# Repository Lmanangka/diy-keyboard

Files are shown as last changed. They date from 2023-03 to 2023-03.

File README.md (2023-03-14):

# diy-keyboard

Making and design my own keyboard from scratch

## Design and Components

### Front View Components

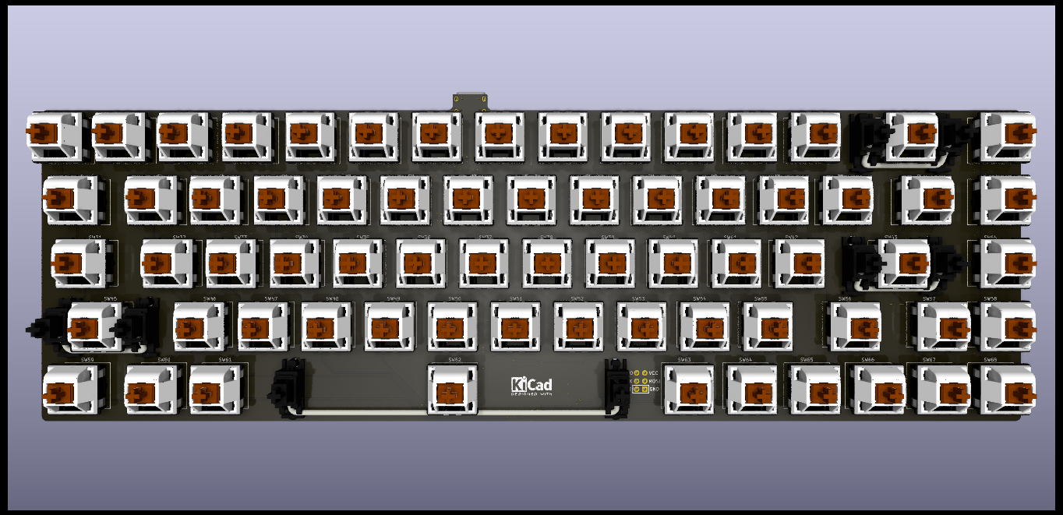
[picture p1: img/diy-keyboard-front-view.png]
Front view


- Switch Cherry MX
- Cherry MX Stabilizer(PCB mount stabs)

### Back View Components

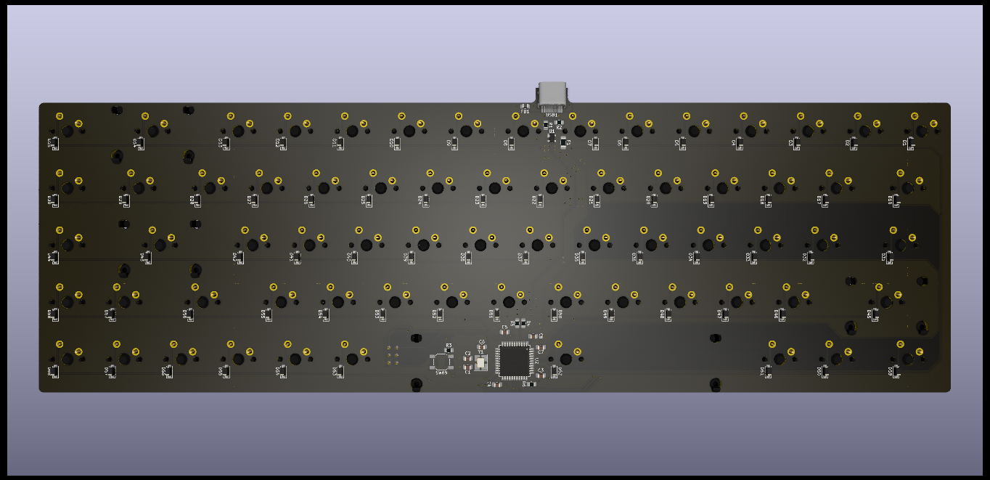
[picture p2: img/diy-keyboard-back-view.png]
Back view

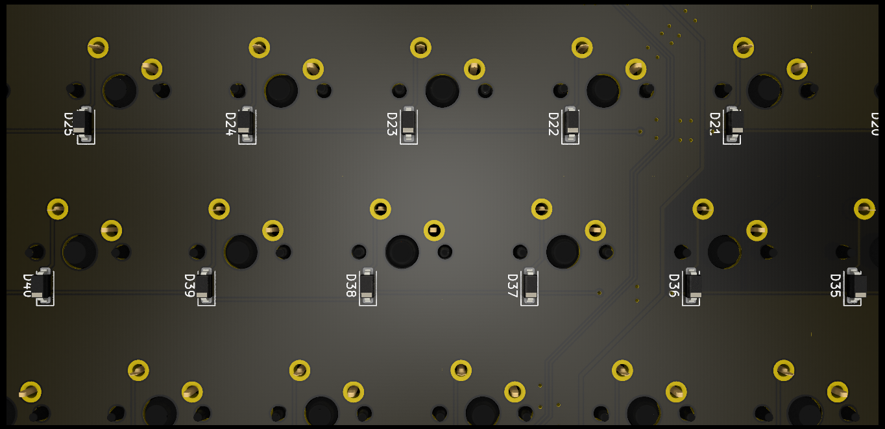
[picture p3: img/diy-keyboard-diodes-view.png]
Diodes view


- Diode 1N4148W

### MCU View Components

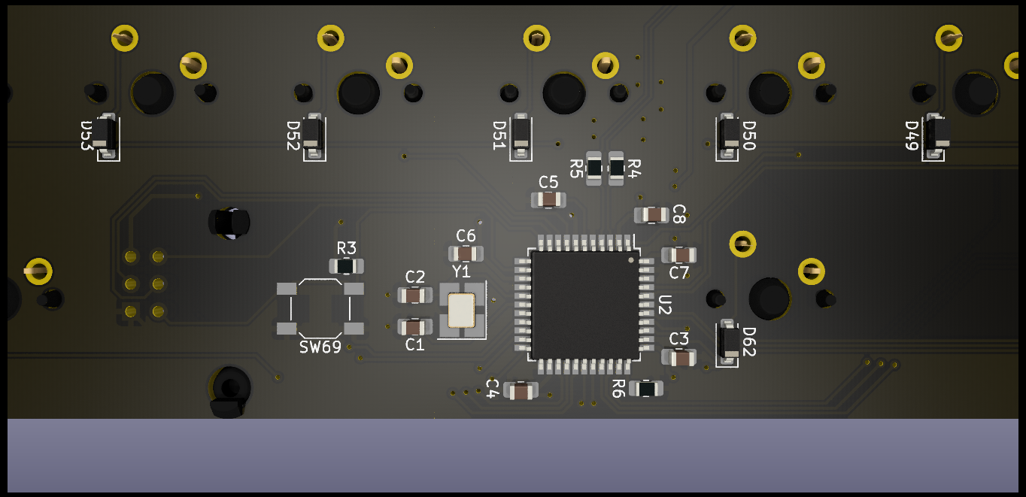
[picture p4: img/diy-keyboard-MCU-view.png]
MCU view


- U2 MCU ATmega32U4-AU
- Y1 Crystal oscilator 16MHz
- SW69 Reset Switch SKQG
- C1-C2 Capacitor 22pF
- C3-C7 Capacitor 0.1uF
- C8 Capacitor 10uF
- R3, R6 Resistor 10K Ohm
- R4-R5 Resistor 22 Ohm
- J1 AVR-ISP Connector

### USB-Type-C View Components

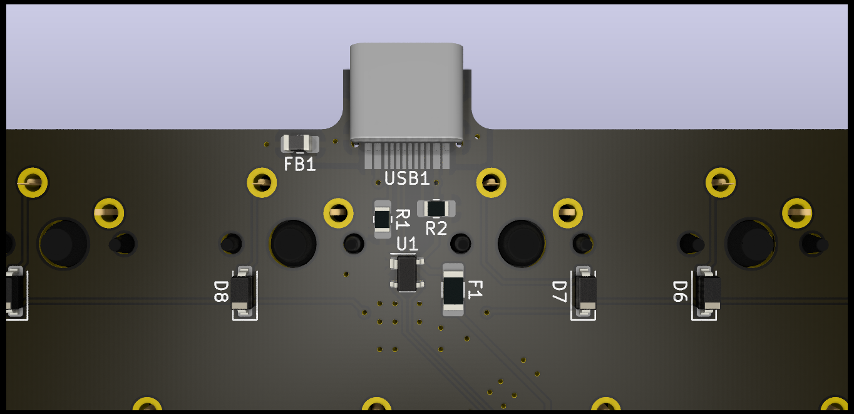
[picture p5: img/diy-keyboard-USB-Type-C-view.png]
USB view


- USB Type C
- FB1 Ferrite Bead
- R1-R2 Resistor 5.1K Ohm
- F1 PTC Fuse 500mA
- U1 PRTR5V0U2X

## Footprints Source

- [Switch and stabilizer](https://github.com/perigoso/keyswitch-kicad-library)
- [USB Type C](https://github.com/ai03-2725/Type-C.pretty)

## References And Credit

- [Designing a keyboard from scratch](https://www.masterzen.fr/2020/05/03/designing-a-keyboard-part-1)(mostly I used this as guide)
- [PCB Designer Guide](https://wiki.ai03.com/books/pcb-design/chapter/pcb-designer-guide)(starting point)
- [keyboard-pcb-guide](https://github.com/ruiqimao/keyboard-pcb-guide)(for reference)

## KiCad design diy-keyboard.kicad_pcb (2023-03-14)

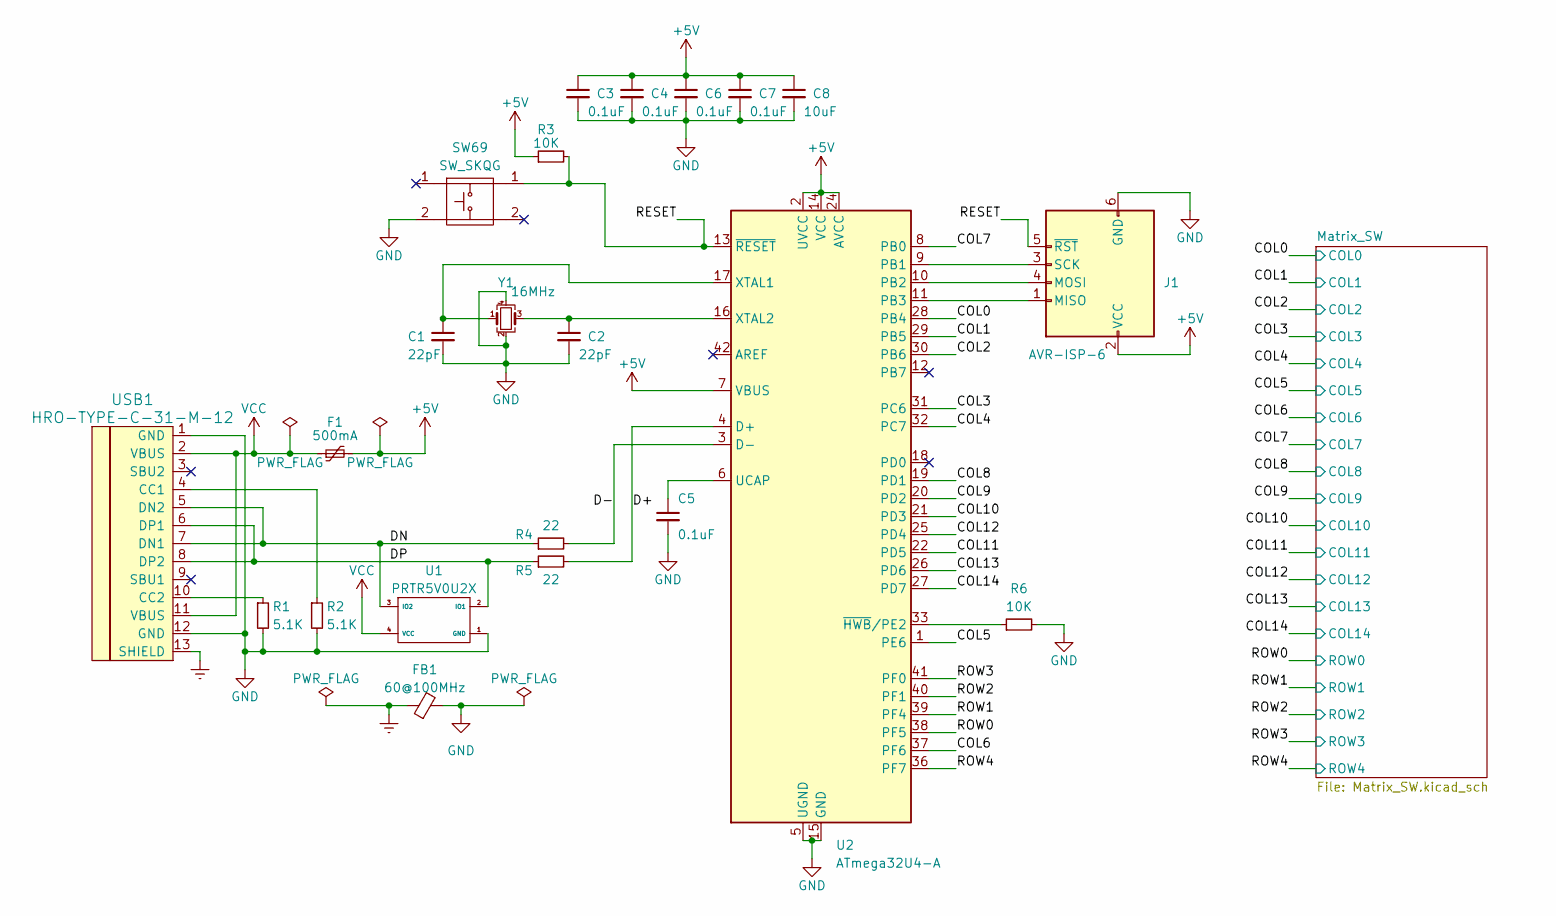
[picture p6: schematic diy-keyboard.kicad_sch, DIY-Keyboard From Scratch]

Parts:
C1, C2: 22pF; C_0805_2012Metric_Pad1.18x1.45mm_HandSolder
C3, C4, C5, C6, C7: 0.1uF; C_0805_2012Metric_Pad1.18x1.45mm_HandSolder
C8: 10uF; C_0805_2012Metric_Pad1.18x1.45mm_HandSolder
F1: 500mA; Fuse_1206_3216Metric_Pad1.42x1.75mm_HandSolder
FB1: 60@100MHz; L_0805_2012Metric_Pad1.15x1.40mm_HandSolder
J1: AVR-ISP-6; Reset_Pretty-Mask
R1, R2: 5.1K; R_0805_2012Metric_Pad1.20x1.40mm_HandSolder
R3, R6: 10K; R_0805_2012Metric_Pad1.20x1.40mm_HandSolder
R4, R5: 22; R_0805_2012Metric_Pad1.20x1.40mm_HandSolder
SW69: SW_SKQG; SW_SPST_SKQG_WithStem
U1: PRTR5V0U2X; SOT-143
U2: ATmega32U4-A; TQFP-44_10x10mm_P0.8mm
USB1: HRO-TYPE-C-31-M-12; HRO-TYPE-C-31-M-12-HandSoldering
Y1: 16MHz; Crystal_SMD_3225-4Pin_3.2x2.5mm_HandSoldering

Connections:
+5V: C3.1, C4.1, C6.1, C7.1, C8.1, F1.2, J1.2 (VCC), R3.1, U2.2 (UVCC), U2.7 (VBUS), U2.14 (VCC), U2.24 (AVCC), U2.34 (VCC), U2.44 (AVCC)
/COL0: U2.28 (PB4); also elsewhere on the board
/COL1: U2.29 (PB5); also elsewhere on the board
/COL2: U2.30 (PB6); also elsewhere on the board
/COL3: U2.31 (PC6); also elsewhere on the board
/COL4: U2.32 (PC7); also elsewhere on the board
/COL5: U2.1 (PE6); also elsewhere on the board
/COL6: U2.37 (PF6); also elsewhere on the board
/COL7: U2.8 (PB0); also elsewhere on the board
/COL8: U2.19 (PD1); also elsewhere on the board
/COL9: U2.20 (PD2); also elsewhere on the board
/COL10: U2.21 (PD3); also elsewhere on the board
/COL11: U2.22 (PD5); also elsewhere on the board
/COL12: U2.25 (PD4); also elsewhere on the board
/COL13: U2.26 (PD6); also elsewhere on the board
/COL14: U2.27 (PD7); also elsewhere on the board
/D+: R5.2, U2.4 (D+)
/D-: R4.2, U2.3 (D-)
/DN: R4.1, U1.3 (IO2), USB1.5 (DN2), USB1.7 (DN1)
/DP: R5.1, U1.2 (IO1), USB1.6 (DP1), USB1.8 (DP2)
/RESET: J1.5 (~RST), R3.2, SW69.1, U2.13 (~RESET)
/ROW0: U2.38 (PF5); also elsewhere on the board
/ROW1: U2.39 (PF4); also elsewhere on the board
/ROW2: U2.40 (PF1); also elsewhere on the board
/ROW3: U2.41 (PF0); also elsewhere on the board
/ROW4: U2.36 (PF7); also elsewhere on the board
Earth: FB1.1, USB1.13 (SHIELD)
GND: C1.2, C2.2, C3.2, C4.2, C5.2, C6.2, C7.2, C8.2, FB1.2, J1.6 (GND), R1.2, R2.2, R6.2, SW69.2, U1.1 (GND), U2.5 (UGND), U2.15 (GND), U2.23 (GND), U2.35 (GND), U2.43 (GND), USB1.1 (GND), USB1.12 (GND), Y1.2, Y1.4
unnamed: J1.1 (MISO), U2.11 (PB3)
unnamed: J1.4 (MOSI), U2.10 (PB2)
unnamed: J1.3 (SCK), U2.9 (PB1)
unnamed: C5.1, U2.6 (UCAP)
unnamed: C1.1, U2.17 (XTAL1), Y1.1
unnamed: C2.1, U2.16 (XTAL2), Y1.3
unnamed: R6.1, U2.33 (~HWB/PE2)
unnamed: R2.1, USB1.4 (CC1)
unnamed: R1.1, USB1.10 (CC2)
VCC: F1.1, U1.4 (VCC), USB1.2 (VBUS), USB1.11 (VBUS)

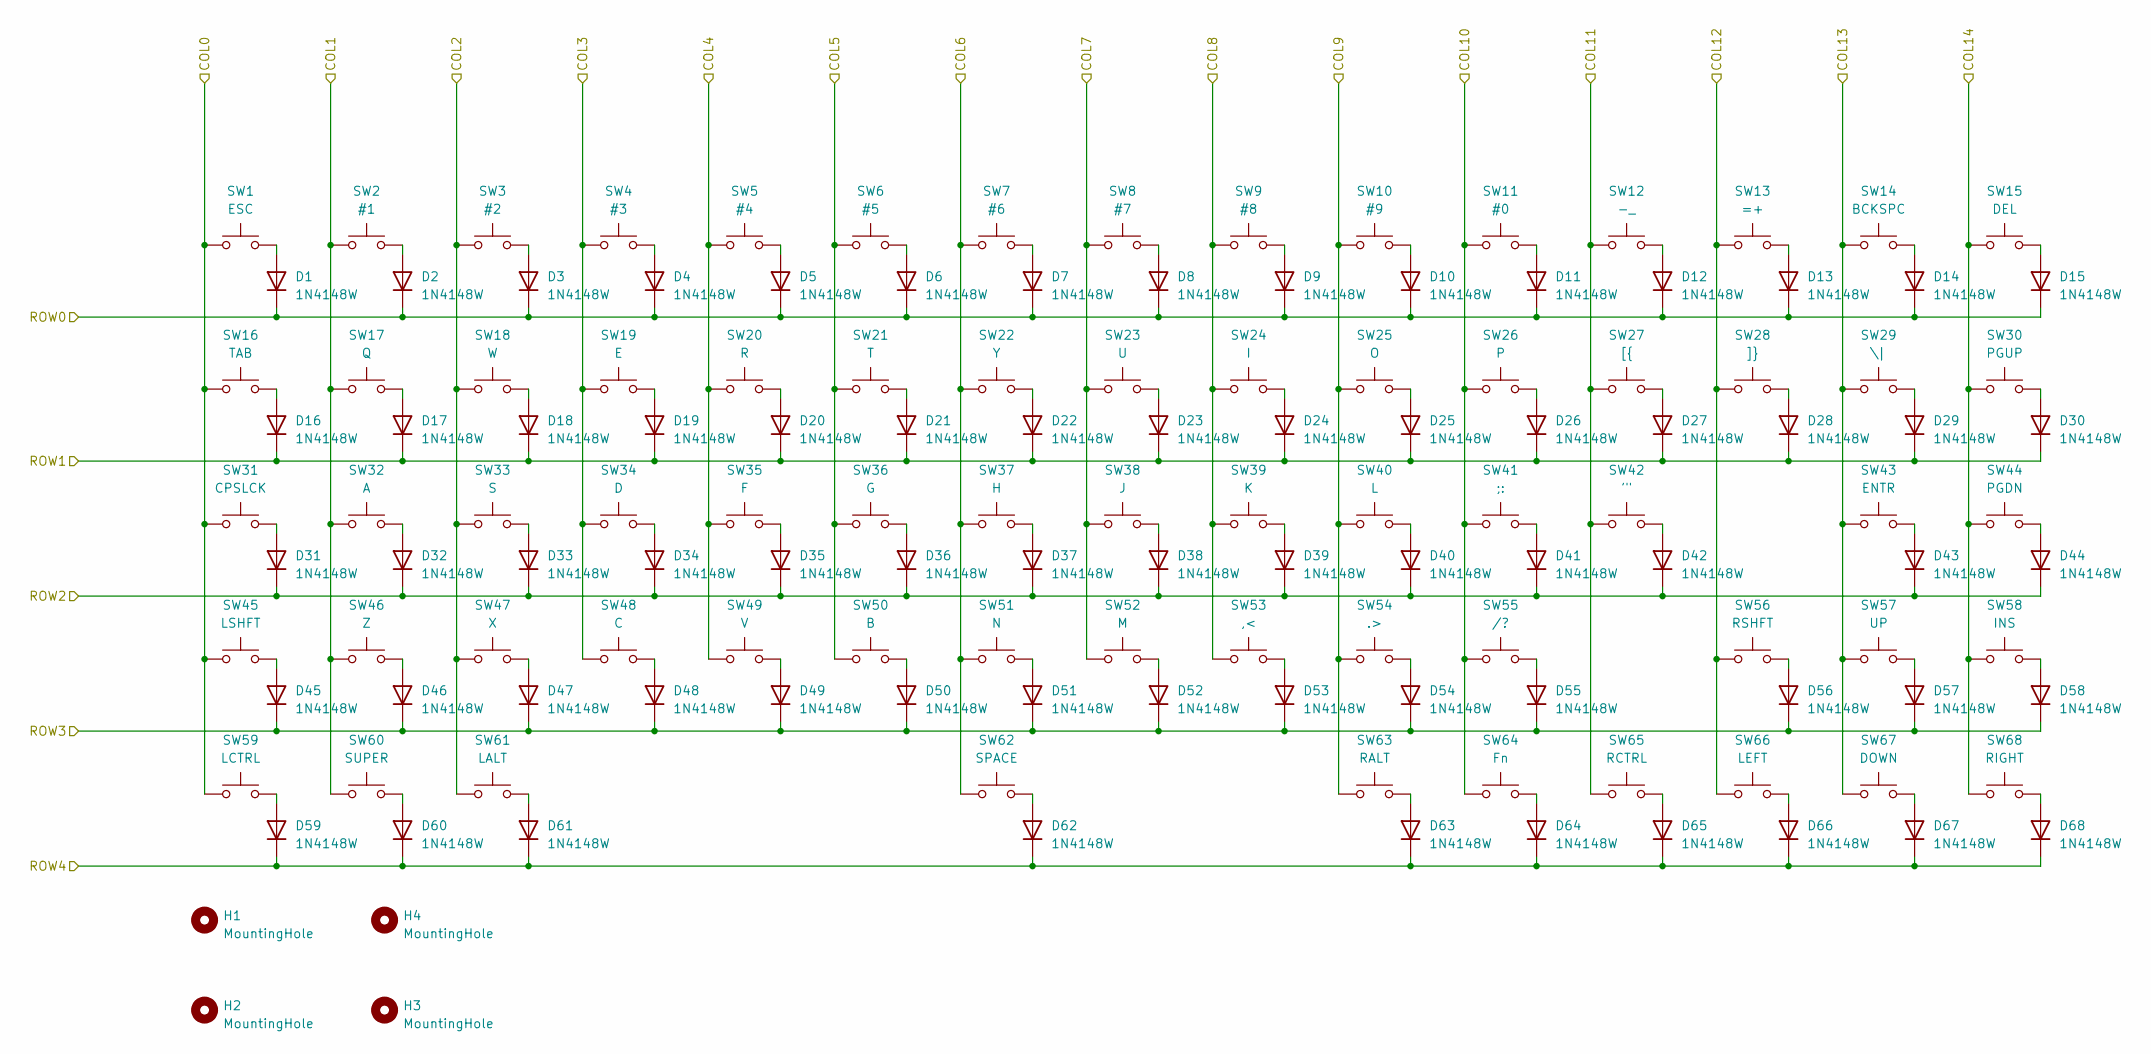
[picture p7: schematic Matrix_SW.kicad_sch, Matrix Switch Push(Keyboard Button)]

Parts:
D1, D2, D3, D4, D5, D6, D7, D8, D9, D10, D11, D12, D13, D14, D15, D16, D17, D18, D19, D20, D21, D22, D23, D24, D25, D26, D27, D28, D29, D30, D31, D32, D33, D34, D35, D36, D37, D38, D39, D40, D41, D42, D43, D44, D45, D46, D47, D48, D49, D50, D51, D52, D53, D54, D55, D56, D57, D58, D59, D60, D61, D62, D63, D64, D65, D66, D67, D68: 1N4148W; D_SOD-123
H1: MountingHole; Stabilizer_Cherry_MX_6.25u
H2, H3, H4: MountingHole; Stabilizer_Cherry_MX_2.00u
SW1: ESC; SW_Cherry_MX_PCB_1.00u
SW2: #1; SW_Cherry_MX_PCB_1.00u
SW3: #2; SW_Cherry_MX_PCB_1.00u
SW4: #3; SW_Cherry_MX_PCB_1.00u
SW5: #4; SW_Cherry_MX_PCB_1.00u
SW6: #5; SW_Cherry_MX_PCB_1.00u
SW7: #6; SW_Cherry_MX_PCB_1.00u
SW8: #7; SW_Cherry_MX_PCB_1.00u
SW9: #8; SW_Cherry_MX_PCB_1.00u
SW10: #9; SW_Cherry_MX_PCB_1.00u
SW11: #0; SW_Cherry_MX_PCB_1.00u
SW12: -_; SW_Cherry_MX_PCB_1.00u
SW13: =+; SW_Cherry_MX_PCB_1.00u
SW14: BCKSPC; SW_Cherry_MX_PCB_2.00u
SW15: DEL; SW_Cherry_MX_PCB_1.00u
SW16: TAB; SW_Cherry_MX_PCB_1.50u
SW17: Q; SW_Cherry_MX_PCB_1.00u
SW18: W; SW_Cherry_MX_PCB_1.00u
SW19: E; SW_Cherry_MX_PCB_1.00u
SW20: R; SW_Cherry_MX_PCB_1.00u
SW21: T; SW_Cherry_MX_PCB_1.00u
SW22: Y; SW_Cherry_MX_PCB_1.00u
SW23: U; SW_Cherry_MX_PCB_1.00u
SW24: I; SW_Cherry_MX_PCB_1.00u
SW25: O; SW_Cherry_MX_PCB_1.00u
SW26: P; SW_Cherry_MX_PCB_1.00u
SW27: [{; SW_Cherry_MX_PCB_1.00u
SW28: ]}; SW_Cherry_MX_PCB_1.00u
SW29: \|; SW_Cherry_MX_PCB_1.50u
SW30: PGUP; SW_Cherry_MX_PCB_1.00u
SW31: CPSLCK; SW_Cherry_MX_PCB_1.75u
SW32: A; SW_Cherry_MX_PCB_1.00u
SW33: S; SW_Cherry_MX_PCB_1.00u
SW34: D; SW_Cherry_MX_PCB_1.00u
SW35: F; SW_Cherry_MX_PCB_1.00u
SW36: G; SW_Cherry_MX_PCB_1.00u
SW37: H; SW_Cherry_MX_PCB_1.00u
SW38: J; SW_Cherry_MX_PCB_1.00u
SW39: K; SW_Cherry_MX_PCB_1.00u
SW40: L; SW_Cherry_MX_PCB_1.00u
SW41: ;:; SW_Cherry_MX_PCB_1.00u
SW42: '"; SW_Cherry_MX_PCB_1.00u
SW43: ENTR; SW_Cherry_MX_PCB_2.25u
SW44: PGDN; SW_Cherry_MX_PCB_1.00u
SW45: LSHFT; SW_Cherry_MX_PCB_2.25u
SW46: Z; SW_Cherry_MX_PCB_1.00u
SW47: X; SW_Cherry_MX_PCB_1.00u
SW48: C; SW_Cherry_MX_PCB_1.00u
SW49: V; SW_Cherry_MX_PCB_1.00u
SW50: B; SW_Cherry_MX_PCB_1.00u
SW51: N; SW_Cherry_MX_PCB_1.00u
SW52: M; SW_Cherry_MX_PCB_1.00u
SW53: ,<; SW_Cherry_MX_PCB_1.00u
SW54: .>; SW_Cherry_MX_PCB_1.00u
SW55: /?; SW_Cherry_MX_PCB_1.00u
SW56: RSHFT; SW_Cherry_MX_PCB_1.75u
SW57: UP; SW_Cherry_MX_PCB_1.00u
SW58: INS; SW_Cherry_MX_PCB_1.00u
SW59: LCTRL; SW_Cherry_MX_PCB_1.50u
SW60: SUPER; SW_Cherry_MX_PCB_1.00u
SW61: LALT; SW_Cherry_MX_PCB_1.00u
SW62: SPACE; SW_Cherry_MX_PCB_6.50u
SW63: RALT; SW_Cherry_MX_PCB_1.00u
SW64: Fn; SW_Cherry_MX_PCB_1.00u
SW65: RCTRL; SW_Cherry_MX_PCB_1.00u
SW66: LEFT; SW_Cherry_MX_PCB_1.00u
SW67: DOWN; SW_Cherry_MX_PCB_1.00u
SW68: RIGHT; SW_Cherry_MX_PCB_1.00u

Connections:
/COL0: SW1.1, SW16.1, SW31.1, SW45.1, SW59.1; also elsewhere on the board
/COL1: SW2.1, SW17.1, SW32.1, SW46.1, SW60.1; also elsewhere on the board
/COL2: SW3.1, SW18.1, SW33.1, SW47.1, SW61.1; also elsewhere on the board
/COL3: SW4.1, SW19.1, SW34.1, SW48.1; also elsewhere on the board
/COL4: SW5.1, SW20.1, SW35.1, SW49.1; also elsewhere on the board
/COL5: SW6.1, SW21.1, SW36.1, SW50.1; also elsewhere on the board
/COL6: SW7.1, SW22.1, SW37.1, SW51.1, SW62.1; also elsewhere on the board
/COL7: SW8.1, SW23.1, SW38.1, SW52.1; also elsewhere on the board
/COL8: SW9.1, SW24.1, SW39.1, SW53.1; also elsewhere on the board
/COL9: SW10.1, SW25.1, SW40.1, SW54.1, SW63.1; also elsewhere on the board
/COL10: SW11.1, SW26.1, SW41.1, SW55.1, SW64.1; also elsewhere on the board
/COL11: SW12.1, SW27.1, SW42.1, SW65.1; also elsewhere on the board
/COL12: SW13.1, SW28.1, SW56.1, SW66.1; also elsewhere on the board
/COL13: SW14.1, SW29.1, SW43.1, SW57.1, SW67.1; also elsewhere on the board
/COL14: SW15.1, SW30.1, SW44.1, SW58.1, SW68.1; also elsewhere on the board
/ROW0: D1.1 (K), D2.1 (K), D3.1 (K), D4.1 (K), D5.1 (K), D6.1 (K), D7.1 (K), D8.1 (K), D9.1 (K), D10.1 (K), D11.1 (K), D12.1 (K), D13.1 (K), D14.1 (K), D15.1 (K); also elsewhere on the board
/ROW1: D16.1 (K), D17.1 (K), D18.1 (K), D19.1 (K), D20.1 (K), D21.1 (K), D22.1 (K), D23.1 (K), D24.1 (K), D25.1 (K), D26.1 (K), D27.1 (K), D28.1 (K), D29.1 (K), D30.1 (K); also elsewhere on the board
/ROW2: D31.1 (K), D32.1 (K), D33.1 (K), D34.1 (K), D35.1 (K), D36.1 (K), D37.1 (K), D38.1 (K), D39.1 (K), D40.1 (K), D41.1 (K), D42.1 (K), D43.1 (K), D44.1 (K); also elsewhere on the board
/ROW3: D45.1 (K), D46.1 (K), D47.1 (K), D48.1 (K), D49.1 (K), D50.1 (K), D51.1 (K), D52.1 (K), D53.1 (K), D54.1 (K), D55.1 (K), D56.1 (K), D57.1 (K), D58.1 (K); also elsewhere on the board
/ROW4: D59.1 (K), D60.1 (K), D61.1 (K), D62.1 (K), D63.1 (K), D64.1 (K), D65.1 (K), D66.1 (K), D67.1 (K), D68.1 (K); also elsewhere on the board
unnamed: D1.2 (A), SW1.2
unnamed: D2.2 (A), SW2.2
unnamed: D3.2 (A), SW3.2
unnamed: D4.2 (A), SW4.2
unnamed: D5.2 (A), SW5.2
unnamed: D6.2 (A), SW6.2
unnamed: D7.2 (A), SW7.2
unnamed: D8.2 (A), SW8.2
unnamed: D9.2 (A), SW9.2
unnamed: D10.2 (A), SW10.2
unnamed: D11.2 (A), SW11.2
unnamed: D12.2 (A), SW12.2
unnamed: D13.2 (A), SW13.2
unnamed: D14.2 (A), SW14.2
unnamed: D15.2 (A), SW15.2
unnamed: D16.2 (A), SW16.2
unnamed: D17.2 (A), SW17.2
unnamed: D18.2 (A), SW18.2
unnamed: D19.2 (A), SW19.2
unnamed: D20.2 (A), SW20.2
unnamed: D21.2 (A), SW21.2
unnamed: D22.2 (A), SW22.2
unnamed: D23.2 (A), SW23.2
unnamed: D24.2 (A), SW24.2
unnamed: D25.2 (A), SW25.2
unnamed: D26.2 (A), SW26.2
unnamed: D27.2 (A), SW27.2
unnamed: D28.2 (A), SW28.2
unnamed: D29.2 (A), SW29.2
unnamed: D30.2 (A), SW30.2
unnamed: D31.2 (A), SW31.2
unnamed: D32.2 (A), SW32.2
unnamed: D33.2 (A), SW33.2
unnamed: D34.2 (A), SW34.2
unnamed: D35.2 (A), SW35.2
unnamed: D36.2 (A), SW36.2
unnamed: D37.2 (A), SW37.2
unnamed: D38.2 (A), SW38.2
unnamed: D39.2 (A), SW39.2
unnamed: D40.2 (A), SW40.2
unnamed: D41.2 (A), SW41.2
unnamed: D42.2 (A), SW42.2
unnamed: D43.2 (A), SW43.2
unnamed: D44.2 (A), SW44.2
unnamed: D45.2 (A), SW45.2
unnamed: D46.2 (A), SW46.2
unnamed: D47.2 (A), SW47.2
unnamed: D48.2 (A), SW48.2
unnamed: D49.2 (A), SW49.2
unnamed: D50.2 (A), SW50.2
unnamed: D51.2 (A), SW51.2
unnamed: D52.2 (A), SW52.2
unnamed: D53.2 (A), SW53.2
unnamed: D54.2 (A), SW54.2
unnamed: D55.2 (A), SW55.2
unnamed: D56.2 (A), SW56.2
unnamed: D57.2 (A), SW57.2
unnamed: D58.2 (A), SW58.2
unnamed: D59.2 (A), SW59.2
unnamed: D60.2 (A), SW60.2
unnamed: D61.2 (A), SW61.2
unnamed: D62.2 (A), SW62.2
unnamed: D63.2 (A), SW63.2
unnamed: D64.2 (A), SW64.2
unnamed: D65.2 (A), SW65.2
unnamed: D66.2 (A), SW66.2
unnamed: D67.2 (A), SW67.2
unnamed: D68.2 (A), SW68.2

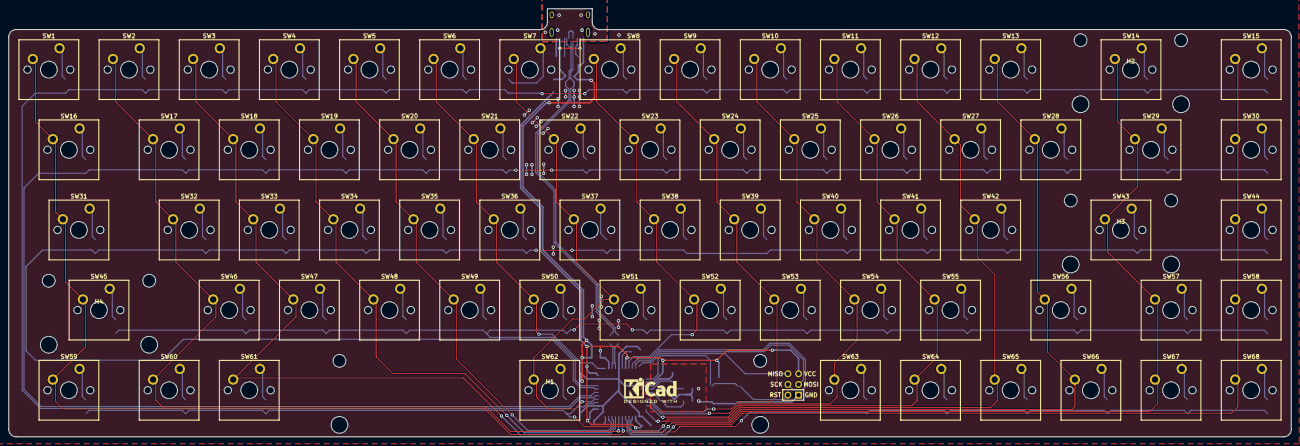
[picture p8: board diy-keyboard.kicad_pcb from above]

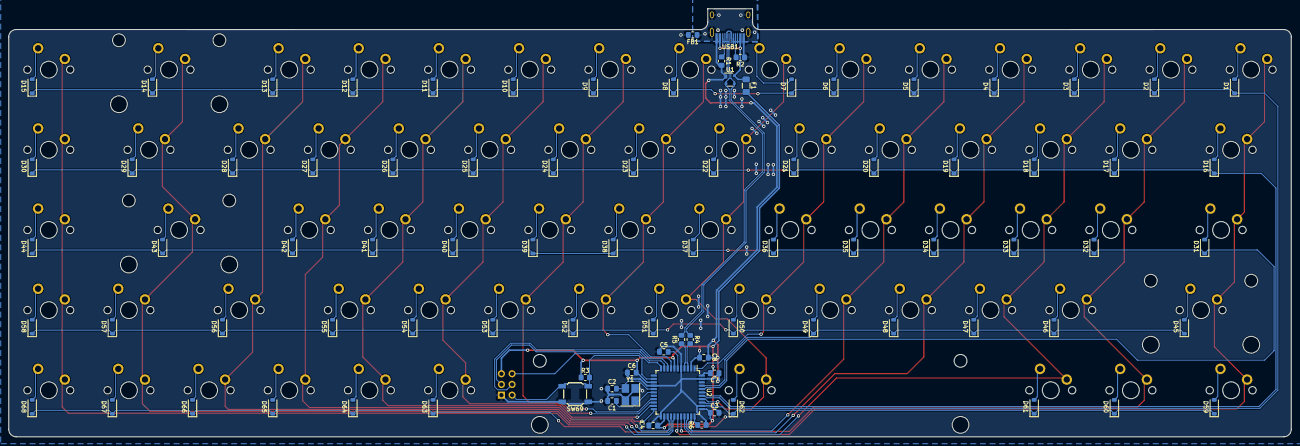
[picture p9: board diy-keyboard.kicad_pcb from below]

Board: 2 copper layers, 304.8 x 101.7 mm, 162 parts (89 on the bottom side), 106 nets.

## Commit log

2023-03-07 add kicad files
    [diy-keyboard.kicad_pcb, diy-keyboard.kicad_sch]
2023-03-07 Add diy-keyboard.kicad_prl to .gitignore
2023-03-07 Add footprint libraries
2023-03-08 Remove submodule
    [diy-keyboard.kicad_sch]
2023-03-08 Add Cherry MX and Mounting keyboard stabilizer footprint
2023-03-08 Add button SW_SKQG library
2023-03-08 Add ESD protection PRTR5V0U2X footprint
2023-03-08 Add keyboard button matrix schematic
    [Matrix_SW.kicad_sch]
2023-03-08 Update Library and schematic
    [diy-keyboard.kicad_sch]
2023-03-08 Update schematic connecting matrix keyboard switch to MCU
    [diy-keyboard.kicad_sch]
2023-03-08 Assigning footprint to components
    [Matrix_SW.kicad_sch, diy-keyboard.kicad_sch]
2023-03-09 Change keyboard layout and reasign keyboard footprints
    [Matrix_SW.kicad_sch]
2023-03-09 Making edge cuts PCB taking a shape
    [diy-keyboard.kicad_pcb, diy-keyboard.kicad_sch]
2023-03-10 Routing switch and diode
    [diy-keyboard.kicad_pcb]
2023-03-10 Add label for diferential pair
    [diy-keyboard.kicad_sch]
2023-03-10 Routing USB and Crystal Oscillator
    [diy-keyboard.kicad_pcb]
2023-03-10 Reassign footprint SW59 and re-allign keyboard layout
    [Matrix_SW.kicad_sch, diy-keyboard.kicad_pcb, diy-keyboard.kicad_sch]
2023-03-12 Change Diode to more specific type 1N4148 SOD-123
    [Matrix_SW.kicad_sch]
2023-03-12 Change diode footprint to 1N4148 SOD-123 and re-routing PCB
    [diy-keyboard.kicad_pcb, diy-keyboard.kicad_sch]
2023-03-12 Re-organize local footprint library
2023-03-12 Re-assign symbol and footprint to match local library
    [Matrix_SW.kicad_sch, diy-keyboard.kicad_pcb, diy-keyboard.kicad_sch]
2023-03-12 Adding ferrite bead to usb sield
    [diy-keyboard.kicad_sch]
2023-03-12 Routing usb shield to ferrite bead
    [diy-keyboard.kicad_pcb]
2023-03-14 Add kicad logo
    [diy-keyboard.kicad_pcb]
